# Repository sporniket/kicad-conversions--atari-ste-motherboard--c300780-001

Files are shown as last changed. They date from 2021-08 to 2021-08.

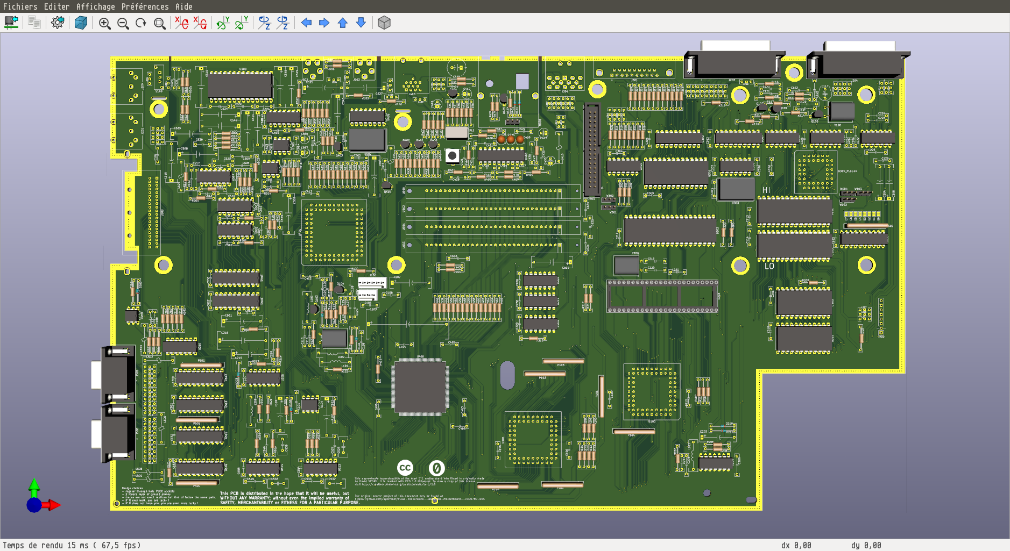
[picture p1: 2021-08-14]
gallery/02--pcb-render-overview-front.png

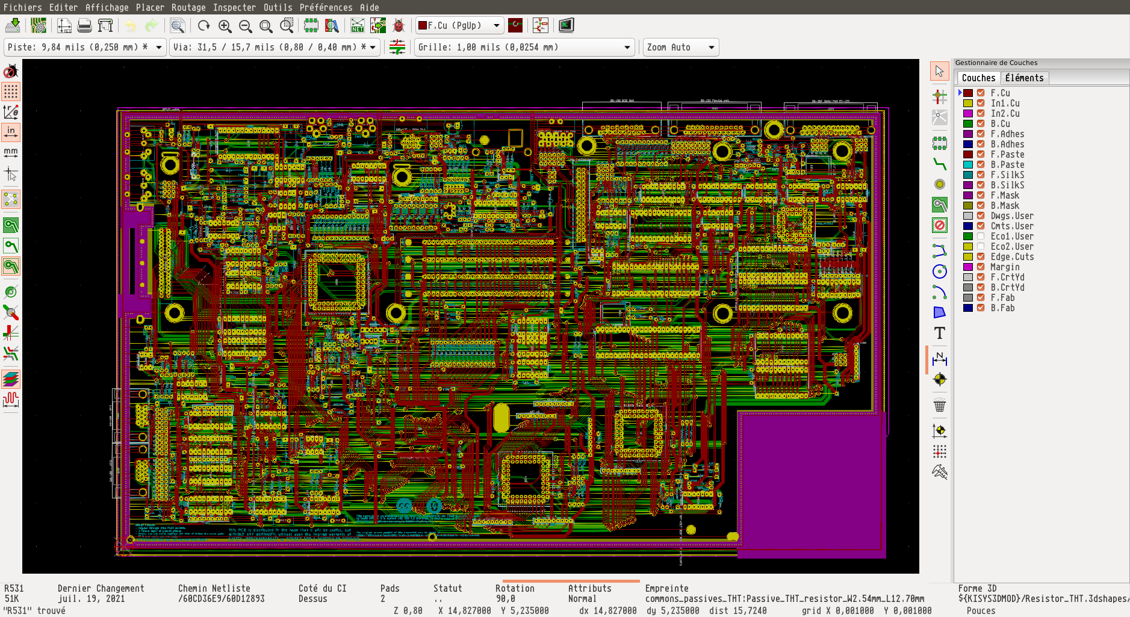
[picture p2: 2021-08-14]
gallery/01--pcbnews-overview.png

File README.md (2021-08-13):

# Sporniket's conversion of the schematics of the 'Atari STE' computer into Kicad

> [WARNING] Please read carefully this note before using this project. It contains important facts.

Content

1. What is **Sporniket's conversion of the schematics of the 'Atari STE' computer into Kicad**, and when to use it ?
2. What should you know before using **Sporniket's conversion of the schematics of the 'Atari STE' computer into Kicad** ?
3. How to use **Sporniket's conversion of the schematics of the 'Atari STE' computer into Kicad** ?
4. Known issues
5. Miscellanous

## 1. What is **Sporniket's conversion of the schematics of the 'Atari STE' computer into Kicad**, and when to use it ?

As the name implies **Sporniket's conversion of the schematics of the 'Atari STE' computer into Kicad** is a project made with [Kicad](https://www.kicad.org/). I converted the available schematics of a computer from 1989 called 'Atari STe', and there is even a PCB to serve as a non normative reference.

### Licence

**Sporniket's conversion of the schematics of the 'Atari STE' computer into Kicad** is marked with CC0 1.0 Universal. To view a copy of this license, visit http://creativecommons.org/publicdomain/zero/1.0

**Sporniket's conversion of the schematics of the 'Atari STE' computer into Kicad** is distributed in the hope that it will be useful, but WITHOUT ANY WARRANTY; without even the implied warranty of MERCHANTABILITY or FITNESS FOR A PARTICULAR PURPOSE.

## 2. What should you know before using **Sporniket's conversion of the schematics of the 'Atari STE' computer into Kicad** ?

As the name implies, **Sporniket's conversion of the schematics of the 'Atari STE' computer into Kicad** is made using [Kicad](https://www.kicad.org/).

The git repository use several submodules that one has to fetch in order to get the symbols, footprint and 3dmodels. One submodule requires [python3](https://www.python.org) and [GNU make](https://www.gnu.org/software/make/) to generate the libraries of symbols for integrated circuits.

This project contains a PCB design that is an **approximate reconstruction** :

* Component and mounting hole placement was **approximatively** guided by a degraded silk screen and solder mask found on a scanned service manual.
* Routing has been **approximatively** guided by a series of shots of the component side and solder sides of an actual motherboard, covering all the surface.

> Do not use **Sporniket's conversion of the schematics of the 'Atari STE' computer into Kicad** if this project is not suitable for your project.

## 3. How to use **Sporniket's conversion of the schematics of the 'Atari STE' computer into Kicad** ?

### From sources

To get the latest available models, one must clone the git repository **and the submodules**. Then some modules needs a build step to generate its libraries.

	git clone --recurse-submodules https://github.com/sporniket/kicad-conversions--atari-ste-motherboard--c300780-001.git
	cd kicad-conversions--atari-ste-motherboard--c300780-001/kicad-symbols-generated
	make

Then, open the project in Kicad.

### From github releases

A github releases will provide :

* A standalone Kicad project (all custom libraries included and ready to use)
* A PDF of the schematics
* A PDF of the silkscreen

## 4. Known issues
See the [project issues](https://github.com/sporniket/kicad-conversions--atari-ste-motherboard--c300780-001/issues) page.

## 5. Miscellanous

### Report issues
Use the [project issues](https://github.com/sporniket/kicad-conversions--atari-ste-motherboard--c300780-001/issues) page.

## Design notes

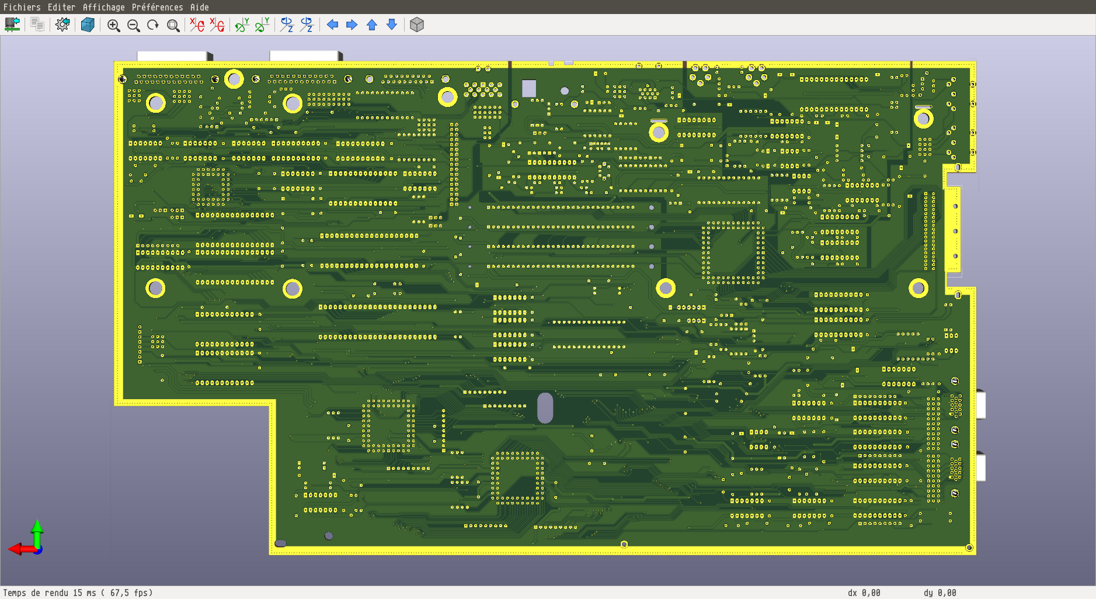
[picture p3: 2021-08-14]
gallery/03--pcb-render-overview-back.png

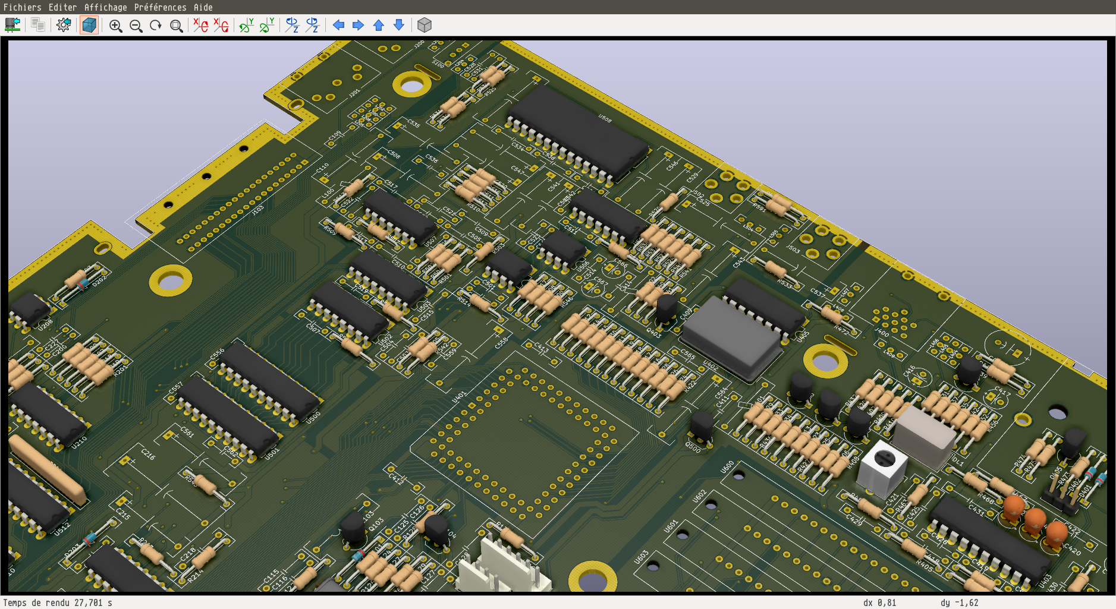
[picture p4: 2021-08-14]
gallery/04--pcb-raytrace-north-west.png

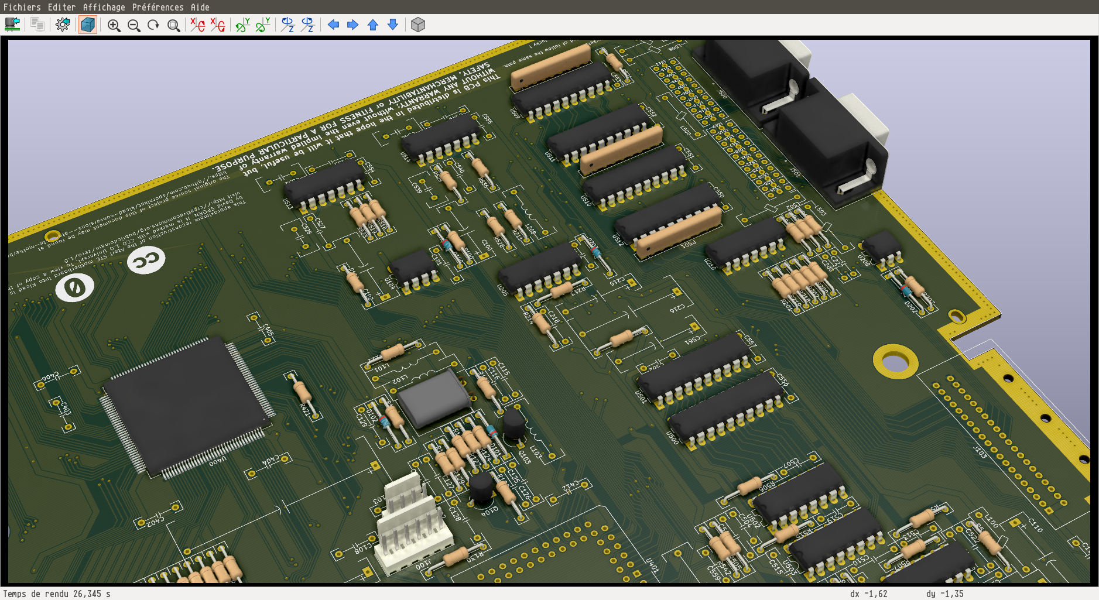
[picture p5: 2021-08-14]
gallery/07--pcb-raytrace-south-west.png

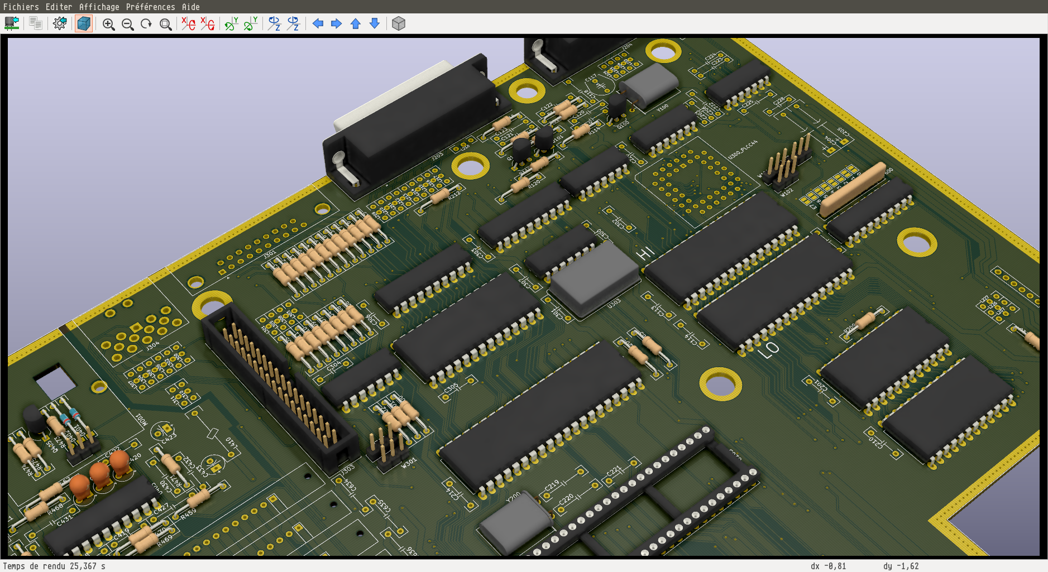
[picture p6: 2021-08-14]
gallery/05--pcb-raytrace-north-east.png

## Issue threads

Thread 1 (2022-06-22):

Annotate the DACs (U502-U503) about sound format

sporniket, 2022-06-22:
[DAC0802 datasheet](https://www.ti.com/lit/ds/symlink/dac0802.pdf)

The MSB (bit 7) from the STE Shifter is inverted before being sent to the DAC.  It seems to me that the DAC is wired for a "Basic Bipolar Output Operation" (see fig. 22 p9 of the datasheet) with the resulting audio signal taken from pin 2 (/E0), see also table 2 p9)

Meaning that the expected sound format is **8 bits PCM signed**

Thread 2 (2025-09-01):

[bug][pcb] fixation holes of the cartridge port should be rotated 90 degres

sporniket, 2025-09-01:
Photo of the holes to change

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

sporniket, 2025-09-03:
Done

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

Closed 2025-09-03.

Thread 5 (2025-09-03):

[bug][schematic] Link local 'VCC' labels to global 'VCC'

sporniket, 2025-09-03:
same as #4

Closed 2025-09-03.

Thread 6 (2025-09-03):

[bug][schematic] Link local '+12V' labels to global '+12V'

sporniket, 2025-09-03:
same as #4

Closed 2025-09-03.

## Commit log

2021-08-03 import gitignore from retro-computer-clean-schematics
2021-08-04 Importing project from retro-computer-clean-schematics
    [motherboard.sch, subsheet_100.sch, subsheet_101.sch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]
2021-08-04 [PCB] routing around extended game port
2021-08-04 [Schematics] swapped R521-R523 and R518-R519 to match the pcb
    [subsheet_500.sch]
2021-08-04 [PCB] routing around the extended game port
2021-08-05 [PCB] routing around the CPU
2021-08-05 [PCB] routing around the CPU and the ACIAs
2021-08-05 [Schematics] added comment about the swap of the resistors between R518 and R521, and between R519 and R523
    [subsheet_500.sch]
2021-08-06 [Schematics] bridged delay lines pins 3 and 6 to match pcb, fixed forgotten R442
    [subsheet_403.sch]
2021-08-06 [PCB] routing around PAL/NTSC encoder
2021-08-07 [PCB] routing around the top and MFP
2021-08-07 Fixed : swapped pad 48 and 49 of GSTMCU
    [subsheet_400.sch]
2021-08-07 [PCB] routing from CPU to Blitter to MCU
2021-08-08 [PCB] routing around the MCU
2021-08-08 [PCB] routing around MFP to Q103
2021-08-08 [Schematics] move relative position of R207 and D202 to match PCB traces
    [subsheet_200.sch]
2021-08-08 [PCB] routing around the Shifter
2021-08-10 [PCB] routing the bus
2021-08-10 [Schematic] swap C105 and C106
    [subsheet_101.sch]
2021-08-10 [PCB] route data bus and other MCU signals
2021-08-10 [PCB] routing various signals, finished north-west area
2021-08-10 [PCB] routing SNDDIR,SNDCS, swapped pads or traces ?
2021-08-11 [Schematics] Fixed : U400 pin 18 and 19 swapped
    [subsheet_400.sch]
2021-08-11 [PCB] route parallel port
2021-08-11 Fixed : R127 is shorted
    [subsheet_106.sch]
2021-08-11 [PCB] routing, serial wires are mixed, to sort out.
2021-08-11 [PCB] finish routing of serial, rdy, etc..., almost done
2021-08-12 [PCB] done routing right part
2021-08-12 [Schematic] Fixed again resistors connected to L500 and L501
    [subsheet_500.sch, subsheet_501.sch]
2021-08-12 [PCB] Done routing, work on ground fills on front side
2021-08-12 [PCB] bordering with vias
2021-08-12 [PCB] cleanstep on the silkscreen
2021-08-12 [PCB] adjust text and logos position CC-0, not over vias
2021-08-12 [PCB] done grounding of front side
2021-08-12 [PCB] using exclusion area on all layer, except some closing limited to back and front
2021-08-12 [PCB] fixed drc errors
2021-08-12 [PCB] fixed drc errors -- not connected items
2021-08-13 [Schematics] add comments to match wiring changes in extended game ports controllers
    [subsheet_501.sch]
2021-08-13 updated comments on the silkscreen
2021-08-13 added reference pictures of actual motherboard, component side and solderside
2021-08-13 [Schematic] mention and reference of the LMC Mixer fix
    [subsheet_504.sch]
2021-08-13 [Schematics] Reference to the fix of video ghosting from Exxos
    [subsheet_402.sch]
2021-08-13 [Schematics] Reference to the WD1772 databus pull-up fix
    [subsheet_302.sch]
2021-08-13 [Schematics] Reference to the LS06 pull-up fix for the floppy drive
    [subsheet_302.sch]
2021-08-14 [Schematics] finalize comment about audio mix fix with reference link to P.P. page
    [subsheet_504.sch]
2021-08-14 [Schematics] graphical details for the pull-ups of drive signals fix
    [subsheet_302.sch]
2021-08-14 Added a note about the presence of comment referencing some hardware fixes
    [motherboard.sch, subsheet_302.sch, subsheet_504.sch]
2021-08-14 [PCB] update layer visibility
2021-08-14 [PCB] fix position of 'C201' reference to match with 'C210'
2021-08-15 prepare release candidate
    [motherboard.sch, subsheet_100.sch, subsheet_101.sch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]
2021-08-15 [PCB] update filled areas
2021-08-15 fixed list of fixes referenced in the main page
    [motherboard.sch]
2021-08-15 [Schematics] reference the fact that C415 is reversed.
    [subsheet_403.sch]
2021-08-31 prepare release 1.0.0 : cartridge, update TOC comment, adjust some references on the front silkscreen
    [motherboard.sch, subsheet_100.sch, subsheet_101.sch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]
2021-08-31 prepare release 1.0.0 : adjust references on the front silkscreen
2025-09-03 Convert to Kicad 7
    [motherboard.kicad_sch, subsheet_100.kicad_sch, subsheet_101.kicad_sch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]
2025-09-03 remove Kicad 5 files
    [motherboard.sch, subsheet_100.sch, subsheet_101.sch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]
2025-09-03 Resolves #2 : [bug][pcb] fixation holes of the cartridge port should be rotated 90 degres
2025-09-03 Resolves #3 : [schematic] annotate video port with signal name
    [subsheet_100.kicad_sch, subsheet_101.kicad_sch, subsheet_102.kicad_sch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]
2025-09-03 Resolves #4 : [bug][schematic] Link local 'GND' labels to global 'GND'
    [subsheet_100.kicad_sch, subsheet_101.kicad_sch, subsheet_102.kicad_sch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]
2025-09-03 Resolves #5 : [bug][schematic] Link local 'VCC' labels to global 'VCC'
    [subsheet_100.kicad_sch, subsheet_101.kicad_sch, subsheet_102.kicad_sch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]
2025-09-03 Resolves #6 : [bug][schematic] Link local '+12V' labels to global '+12V'
    [subsheet_302.kicad_sch, subsheet_402.kicad_sch, subsheet_403.kicad_sch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]
